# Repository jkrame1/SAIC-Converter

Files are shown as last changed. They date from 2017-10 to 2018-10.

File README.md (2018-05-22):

# Betweener

Teensy 3.2-based Analog to Digital conversion device using 2 4922 12-bit DACs for 4 channels of Analog Output

**NOTE** the most current version of the boards are "DAC 1.1.0.fzz" and "Interface 1.1.0.fzz". Everything else in the Hardware folder is either experimental or older versions.

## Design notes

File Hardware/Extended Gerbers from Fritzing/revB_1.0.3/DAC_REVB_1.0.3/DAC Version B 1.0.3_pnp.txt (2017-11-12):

*Pick And Place List
*Company=
*Author=
*eMail=
*
*Project=DAC Version B 1.0.3
*Date=07:28:19
*CreatedBy=Fritzing 0.9.3b.04.19.5c895d327c44a3114e5fcc9d8260daf0cbb52806
*
*
*Coordinates in mm, always center of component
*Origin 0/0=Lower left corner of PCB
*Rotation in degree (0-360, math. pos.)
*
*No;Value;Package;X;Y;Rotation;Side;Name
1;;;16.5767;-91.6637;-90;Bottom;Teensy 3.2
2;;DIP (Dual Inline) [THT];24.2807;-30.8493;180;Bottom;DAC2
3;100;THT;6.32573;-25.3319;180;Bottom;R27
4;;THT;6.02065;-75.879;0;Bottom;Interface Pots
5;;DIP (Dual Inline) [THT];26.2165;-9.64763;0;Bottom;DAC1
6;100k;THT;29.9497;-66.6498;-135;Bottom;R5
7;;;26.4372;-20.1802;0;Bottom;Jumper5
8;33k;THT;31.656;-85.7319;45;Bottom;R2
9;33k;THT;31.7249;-101.42;45;Bottom;R4
10;33k;THT;31.8699;-69.4215;38.362;Bottom;R6
11;100k;THT;31.2558;-82.936;-135;Bottom;R1
12;;;12.3095;-33.9719;0;Bottom;Jumper10
13;;;1.39628;-103.485;90;Bottom;TXT1
14;;THT;12.6294;-9.03944;180;Bottom;CV Out
15;;to-92;29.768;-92.8947;180;Bottom;Q1
16;;to-92;30.287;-75.2711;180;Bottom;Q3
17;;THT;12.6294;-23.6444;180;Bottom;CV in
18;100;THT;6.41604;-23.1108;180;Bottom;R28
19;;THT;7.48086;-43.6565;0;Bottom;Eurorack Power Header
20;100k;THT;29.9068;-49.879;180;Bottom;R7
21;100;THT;6.14567;-29.7997;180;Bottom;R25
22;;;10.5339;-66.9021;0;Bottom;Jumper11
23;;;27.7194;-55.913;0;Bottom;Jumper8
24;33k;THT;31.0255;-47.7067;0;Bottom;R8
25;;;26.5956;-60.3765;0;Bottom;Jumper9
26;;THT;14.8872;-46.7867;0;Bottom;5V Euro
27;;to-92;29.8738;-107.888;180;Bottom;Q2
28;;THT;29.1394;-53.4894;-90;Bottom;J2
29;220;THT;18.8911;-50.0074;90;Bottom;R_LED
30;;;24.828;-20.2958;0;Bottom;Jumper6
31;;THT;21.0411;-58.7489;-90;Bottom;Expander Header
32;;THT;6.14511;-62.956;-180;Bottom;Power and I2C Header
33;;5 mm [THT];21.6206;-44.1159;180;Bottom;LED1
34;100;THT;6.31472;-27.619;180;Bottom;R26
35;;;20.3318;-47.3394;0;Bottom;Jumper7
36;100k;THT;31.0743;-98.5495;-135;Bottom;R3
37;;DIP (Dual Inline) [THT];6.06326;-11.1781;0;Bottom;CV Output Buffer
38;;to-92;29.6147;-44.3502;0;Bottom;Q4

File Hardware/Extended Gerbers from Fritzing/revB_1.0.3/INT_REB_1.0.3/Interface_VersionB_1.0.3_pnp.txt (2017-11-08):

*Pick And Place List
*Company=
*Author=
*eMail=
*
*Project=Interface_VersionB_1.0.3
*Date=13:25:12
*CreatedBy=Fritzing 0.9.3b.04.19.5c895d327c44a3114e5fcc9d8260daf0cbb52806
*
*
*Coordinates in mm, always center of component
*Origin 0/0=Lower left corner of PCB
*Rotation in degree (0-360, math. pos.)
*
*No;Value;Package;X;Y;Rotation;Side;Name
1;;;18.1328;-55.5065;0;Bottom;IMG3
2;;;30.0567;-10.1535;0;Bottom;Hole43
3;;;22.0487;-64.9518;0;Bottom;Jumper3
4;;;26.87;-61.8238;0;Bottom;Jumper2
5;;;29.9156;-34.0012;0;Bottom;Hole17
6;;PG203J [THT];16.7271;-10.609;180;Bottom;PJ8
7;;;29.7745;-45.9251;0;Bottom;Hole14
8;;PG203J [THT];16.6329;-34.8801;180;Bottom;PJ6
9;;THT;18.8004;-75.2325;0;Bottom;R3
10;100k;THT;4.27426;-85.6496;90;Bottom;R28
11;;;6.06777;-21.8657;0;Bottom;Hole41
12;;PG203J [THT];6.17258;-45.3141;0;Bottom;PJ1
13;100k;THT;22.5002;-87.0187;-90;Bottom;R40
14;66k;THT;34.3733;-85.2904;90;Bottom;R30
15;;PG203J [THT];6.2849;-34.8801;180;Bottom;PJ2
16;;DIP (Dual Inline) [THT];26.1603;-102.729;0;Bottom;INPUT SCALER
17;;;18.0555;-55.5681;0;Bottom;IMG2
18;;;25.0615;-82.5947;0;Bottom;IMG1
19;100k;THT;8.96874;-75.996;90;Bottom;R27
20;;;16.8393;-21.8423;0;Bottom;Hole39
21;;THT;23.4244;-24.2646;180;Bottom;CV IN HEADER
22;66k;THT;2.49626;-88.4654;90;Bottom;R29
23;;;16.7217;-10.083;0;Bottom;Hole42
24;;PG203J [THT];16.4449;-45.4868;0;Bottom;PJ5
25;;THT;6.91444;-54.1096;-90;Bottom;J2
26;;;16.51;-46.0663;0;Bottom;Hole13
27;;THT;9.01151;-100.035;180;Bottom;R1
28;;PG203J [THT];29.9916;-34.8801;180;Bottom;PJ10
29;;;6.27944;-10.083;0;Bottom;Hole44
30;;;9.5562;-1.33729;0;Bottom;TXT1
31;66k;THT;16.0867;-108.35;0;Bottom;R36
32;66k;THT;24.4435;-88.8323;90;Bottom;R31
33;;PG203J [THT];29.9444;-21.2284;0;Bottom;PJ11
34;;THT;29.8509;-76.498;0;Bottom;P
35;66k;THT;34.3924;-107.395;90;Bottom;R33
36;100k;THT;27.4204;-88.9556;90;Bottom;R38
37;;;6.20888;-45.9252;0;Bottom;Hole12
38;100k;THT;10.5726;-73.6772;90;Bottom;R25
39;66k;THT;30.8091;-89.0056;-90;Bottom;R34
40;;;16.4395;-34.0012;0;Bottom;Hole16
41;;THT;23.4244;-9.65962;180;Bottom;CV OUT HEADER
42;66k;THT;19.2131;-97.5915;90;Bottom;R35
43;;PG203J [THT];30.109;-10.7501;180;Bottom;PJ12
44;66k;THT;19.8715;-86.485;90;Bottom;R32
45;;THT;3.66889;-66.5274;0;Bottom;USB Breakout
46;;;3.48082;-109.519;0;Bottom;Hole45
47;;PG203J [THT];6.09667;-21.1452;0;Bottom;PJ3
48;;THT;27.4647;-62.9279;0;Bottom;R4
49;;PG203J [THT];16.6329;-21.2392;0;Bottom;PJ7
50;100k;THT;15.8767;-110.627;0;Bottom;R39
51;;;19.3088;-73.5712;0;Bottom;Jumper1
52;;PG203J [THT];6.43561;-10.5494;180;Bottom;PJ4
53;;THT;11.8767;-87.5704;0;Bottom;R2
54;100k;THT;32.7268;-105.42;-90;Bottom;R26
55;;;6.20888;-34.0718;0;Bottom;Hole15
56;;;30.0095;-21.8423;0;Bottom;Hole40
57;;PG203J [THT];29.7799;-45.3223;0;Bottom;PJ9
58;100k;THT;33.5326;-95.5159;99.81;Bottom;R37

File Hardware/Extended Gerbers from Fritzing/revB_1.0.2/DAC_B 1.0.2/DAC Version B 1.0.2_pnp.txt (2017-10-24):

*Pick And Place List
*Company=
*Author=
*eMail=
*
*Project=DAC Version B 1.0.2
*Date=15:18:01
*CreatedBy=Fritzing 0.9.3b.04.19.5c895d327c44a3114e5fcc9d8260daf0cbb52806
*
*
*Coordinates in mm, always center of component
*Origin 0/0=Lower left corner of PCB
*Rotation in degree (0-360, math. pos.)
*
*No;Value;Package;X;Y;Rotation;Side;Name
1;33k;THT;31.656;-86.296;45;Bottom;R2
2;100k;THT;31.0743;-99.1136;-135;Bottom;R3
3;;;17.9879;-92.2278;-90;Bottom;Teensy 3.2
4;;;26.7942;-56.1872;0;Bottom;Jumper8
5;;DIP (Dual Inline) [THT];6.06326;-11.7422;0;Bottom;CV Output Buffer
6;100;THT;6.41604;-23.9571;180;Bottom;R28
7;;;25.1531;-21.3863;0;Bottom;Jumper5
8;;;11.6887;-69.8016;0;Bottom;Jumper2
9;;;8.92951;-29.8699;0;Bottom;Jumper3
10;;THT;12.6294;-24.2086;180;Bottom;CV in
11;;to-92;30.287;-75.8352;180;Bottom;Q3
12;;DIP (Dual Inline) [THT];26.2165;-11.6229;0;Bottom;DAC1
13;;;1.6462;-102.972;90;Bottom;TXT1
14;;THT;7.29262;-44.6911;0;Bottom;Eurorack Power Header
15;;;11.66;-29.8488;0;Bottom;Jumper4
16;100;THT;6.32573;-26.1782;180;Bottom;R27
17;;THT;19.2538;-60.4419;-90;Bottom;Expander Header
18;33k;THT;31.7249;-101.984;45;Bottom;R4
19;;;25.2067;-21.4033;0;Bottom;Jumper6
20;100k;THT;31.2558;-83.5001;-135;Bottom;R1
21;;to-92;29.8738;-108.452;180;Bottom;Q2
22;;THT;29.1394;-54.0536;-90;Bottom;J2
23;;THT;12.6294;-9.60356;180;Bottom;J3
24;;THT;6.02065;-76.4431;0;Bottom;Interface Pots
25;;;19.3675;-46.2572;0;Bottom;Jumper7
26;;;28.1869;-60.2272;0;Bottom;Jumper9
27;33k;THT;31.0255;-48.2708;0;Bottom;R8
28;;THT;6.14511;-62.109;-180;Bottom;Power and I2C Header
29;;;11.557;-72.1722;0;Bottom;Jumper1
30;;DIP (Dual Inline) [THT];24.2807;-31.4134;180;Bottom;DAC2
31;;to-92;29.6147;-44.9144;0;Bottom;Q4
32;100;THT;6.28678;-31.0694;180;Bottom;R25
33;100;THT;6.38528;-28.677;180;Bottom;R26
34;;to-92;30.3324;-93.4588;180;Bottom;Q1
35;33k;THT;32.7166;-69.1392;51.9312;Bottom;R6
36;100k;THT;31.4079;-60.8639;-90;Bottom;R5
37;100k;THT;30.4713;-50.5136;180;Bottom;R7

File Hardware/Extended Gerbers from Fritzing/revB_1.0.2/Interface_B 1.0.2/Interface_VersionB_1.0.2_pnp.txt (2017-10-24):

*Pick And Place List
*Company=
*Author=
*eMail=
*
*Project=Interface_VersionB_1.0.2
*Date=22:00:41
*CreatedBy=Fritzing 0.9.3b.04.19.5c895d327c44a3114e5fcc9d8260daf0cbb52806
*
*
*Coordinates in mm, always center of component
*Origin 0/0=Lower left corner of PCB
*Rotation in degree (0-360, math. pos.)
*
*No;Value;Package;X;Y;Rotation;Side;Name
1;;THT;29.851;-76.4979;0;Bottom;Pots
2;66k;THT;19.2131;-97.5915;90;Bottom;R35
3;66k;THT;24.4435;-88.8323;90;Bottom;R31
4;100k;THT;22.5002;-87.0187;-90;Bottom;R40
5;;;29.9156;-34.0012;0;Bottom;Hole17
6;;;20.9411;-89.0859;0;Bottom;IMG1
7;;;30.0095;-21.8423;0;Bottom;Hole40
8;100k;THT;10.5726;-73.6772;90;Bottom;R25
9;;;18.1328;-55.5065;0;Bottom;IMG3
10;;PG203J [THT];6.2849;-34.8801;180;Bottom;PJ2
11;;PG203J [THT];6.09667;-21.1452;0;Bottom;PJ3
12;;PG203J [THT];6.17258;-45.3141;0;Bottom;PJ1
13;;PG203J [THT];29.9916;-34.8801;180;Bottom;PJ10
14;66k;THT;19.0813;-86.8237;90;Bottom;R32
15;;THT;6.91444;-54.1096;-90;Bottom;J2
16;;;16.8393;-21.8423;0;Bottom;Hole39
17;100k;THT;15.8767;-110.627;0;Bottom;R39
18;;;30.0567;-10.1535;0;Bottom;Hole43
19;;;22.0486;-64.9517;0;Bottom;Jumper3
20;;PG203J [THT];29.7799;-45.3223;0;Bottom;PJ9
21;66k;THT;16.0867;-108.35;0;Bottom;R36
22;;;3.48082;-109.519;0;Bottom;Hole45
23;100k;THT;8.96874;-75.996;90;Bottom;R27
24;;;16.4395;-34.0012;0;Bottom;Hole16
25;;THT;11.8767;-87.5704;0;Bottom;R2
26;;THT;27.4647;-62.9279;0;Bottom;R4
27;;PG203J [THT];16.4449;-45.4868;0;Bottom;PJ5
28;;;16.7217;-10.083;0;Bottom;Hole42
29;;;18.0555;-55.5681;0;Bottom;IMG2
30;;PG203J [THT];16.6329;-21.2392;0;Bottom;PJ7
31;;PG203J [THT];6.43561;-10.5494;180;Bottom;PJ4
32;;;6.20888;-45.9252;0;Bottom;Hole12
33;;THT;18.8004;-75.2325;0;Bottom;R3
34;;PG203J [THT];29.9444;-21.2284;0;Bottom;PJ11
35;;;19.3087;-73.5712;0;Bottom;Jumper1
36;;;29.7745;-45.9251;0;Bottom;Hole14
37;100k;THT;27.4204;-88.9555;90;Bottom;R38
38;;;6.20888;-34.0718;0;Bottom;Hole15
39;;DIP (Dual Inline) [THT];26.1603;-102.729;0;Bottom;INPUT SCALER
40;;;16.51;-46.0663;0;Bottom;Hole13
41;;PG203J [THT];16.6329;-34.8801;180;Bottom;PJ6
42;100k;THT;33.589;-95.2337;102.557;Bottom;R37
43;66k;THT;30.8091;-89.0056;-90;Bottom;R34
44;;THT;23.4244;-24.2646;180;Bottom;CV IN HEADER
45;;THT;3.66889;-66.5274;0;Bottom;USB Breakout
46;;THT;23.4244;-9.65962;180;Bottom;CV OUT HEADER
47;;PG203J [THT];16.7271;-10.609;180;Bottom;PJ8
48;66k;THT;2.49626;-88.4654;90;Bottom;R29
49;66k;THT;34.3924;-107.395;90;Bottom;R33
50;66k;THT;34.3733;-85.2904;90;Bottom;R30
51;100k;THT;4.27435;-85.6495;90;Bottom;R28
52;;;26.8699;-61.8237;0;Bottom;Jumper2
53;100k;THT;32.7268;-105.42;-90;Bottom;R26
54;;;6.06777;-21.8657;0;Bottom;Hole41
55;;;6.27944;-10.083;0;Bottom;Hole44
56;;PG203J [THT];30.109;-10.7501;180;Bottom;PJ12
57;;THT;9.01151;-100.035;180;Bottom;R1

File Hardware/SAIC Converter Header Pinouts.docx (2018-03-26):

Betweener Header Pinouts

Betweener V1.1.0

Expansion Header
PIN14 +3.3V | PIN13 GND | PIN12 D8(LED) | PIN11 D33(touch) | PIN10 D31/A20 (serial2 Tx for DINMIDI) | PIN9 D25(touch)PWM | PIN8 D27/A16
PIN1 +5VNC | PIN2 GND | PIN3 A14/DAC | PIN4 D32(touch)/PWM | PIN5 D24 | PIN6 D26/A15(serial2 Rx for DIN MIDI) | PIN7 D28/A17

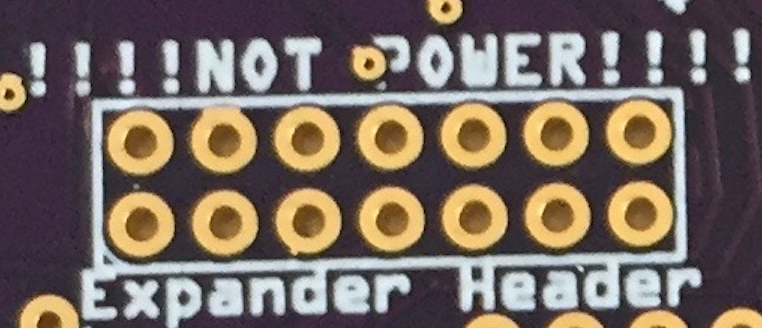
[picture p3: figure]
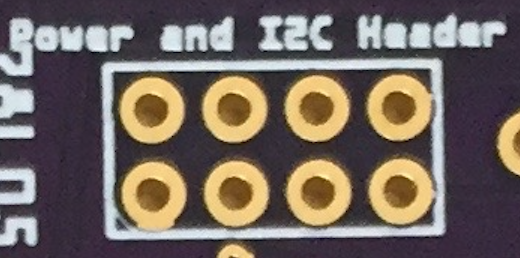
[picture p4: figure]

(bottom end) I²C Header
PIN8 GND | PIN7 +5V | PIN6 +3.3V | PIN5 D29/A18 (SCL1)
PIN1 GND | PIN2 +5V | PIN3 +3.3V | PIN4 D30/A19 (SDA1)

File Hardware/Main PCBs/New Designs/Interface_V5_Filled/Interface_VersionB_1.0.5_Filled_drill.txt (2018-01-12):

; NON-PLATED HOLES START AT T1
; THROUGH (PLATED) HOLES START AT T100
M48
INCH
T1C0.118110
T2C0.125984
T100C0.039370
T101C0.041361
T102C0.125984
T103C0.061825
T104C0.015748
T105C0.035000
T106C0.061867
T107C0.031497
T108C0.088356
T109C0.050165
T110C0.038000
T111C0.041333
%
T1
X002444Y012914
X006583Y003469
X006499Y017636
X002472Y003469
X011833Y003497
X011814Y008099
X006629Y008099
X002444Y017580
X002388Y008108
T2
X011722Y017580
X011777Y012886
X006472Y012886
T100
X008799Y039944
X011799Y038944
X011799Y042944
X011799Y039944
X008799Y036944
X008799Y040944
X008799Y037944
X011799Y036944
X008799Y041944
X011799Y040944
X008799Y038944
X011799Y037944
X008799Y042944
X011799Y041944
T101
X002776Y032972
X005447Y039887
X005502Y028115
X008913Y023270
T102
X001370Y042617
T103
X006550Y004740
X011819Y004796
X002434Y006760
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

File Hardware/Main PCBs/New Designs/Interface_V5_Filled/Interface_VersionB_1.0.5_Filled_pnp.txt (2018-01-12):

*Pick And Place List
*Company=
*Author=
*eMail=
*
*Project=Interface_VersionB_1.0.5_Filled
*Date=14:42:28
*CreatedBy=Fritzing 0.9.3b.04.19.5c895d327c44a3114e5fcc9d8260daf0cbb52806
*
*
*Coordinates in mm, always center of component
*Origin 0/0=Lower left corner of PCB
*Rotation in degree (0-360, math. pos.)
*
*No;Value;Package;X;Y;Rotation;Side;Name
1;;;7.8994;-88.8828;0;Bottom;Copper Fill82
2;;;22.7838;-74.4937;0;Bottom;Copper Fill70
3;;;27.686;-3.88168;0;Bottom;Copper Fill45
4;;;3.48082;-108.249;0;Bottom;Hole45
5;;;15.5194;-12.0732;0;Bottom;Copper Fill101
6;;;20.1041;-80.7929;0;Bottom;Copper Fill93
7;;;31.6738;-14.9561;0;Bottom;Copper Fill38
8;100k;THT;3.99203;-84.6619;90;Bottom;R28
9;;;34.0614;-94.1786;0;Bottom;Copper Fill15
10;;THT;23.4244;-8.38962;180;Bottom;CV OUT HEADER
11;;;15.4178;-41.588;0;Bottom;Copper Fill107
12;;;25.3492;-7.13288;0;Bottom;Copper Fill40
13;;THT;18.8004;-73.9625;0;Bottom;R3
14;66k;THT;1.93181;-87.4776;90;Bottom;R29
15;220;THT;21.0256;-54.1553;0;Bottom;RLED
16;;;17.8308;-89.5051;0;Bottom;Copper Fill18
17;;THT;9.01151;-98.7647;180;Bottom;R1
18;;;22.2885;-82.9519;0;Bottom;Copper Fill94
19;;;2.286;-104.44;0;Bottom;Copper Fill6
20;;;16.51;-29.6881;0;Bottom;Copper Fill33
21;;;32.893;-106.421;0;Bottom;Copper Fill5
22;;;20.1041;-80.7929;0;Bottom;Copper Fill51
23;;;16.4395;-32.7312;0;Bottom;Hole16
24;;;1.8669;-84.5775;0;Bottom;Copper Fill90
25;;;33.8582;-3.19588;0;Bottom;Copper Fill44
26;;THT;6.63222;-55.3091;90;Bottom;J3
27;;;15.4178;-36.3556;0;Bottom;Copper Fill109
28;;;16.6497;-18.3851;0;Bottom;Copper Fill103
29;;PG203J [THT];6.17258;-44.0441;0;Bottom;PJ1
30;;;18.1328;-54.2365;0;Bottom;IMG3
31;100k;THT;22.3591;-85.8193;-90;Bottom;R40
32;;5 mm [THT];12.3194;-61.6163;180;Bottom;LED1
33;;PG203J [THT];6.2849;-33.6101;180;Bottom;PJ2
34;;;34.2138;-74.6715;0;Bottom;Copper Fill23
35;;;16.51;-44.7963;0;Bottom;Hole13
36;;THT;27.4647;-61.6579;0;Bottom;R4
37;;;32.3596;-96.2614;0;Bottom;Copper Fill9
38;;;33.6804;-82.7741;0;Bottom;Copper Fill68
39;;PG203J [THT];16.6329;-33.6101;180;Bottom;PJ6
40;;;33.7312;-77.8719;0;Bottom;Copper Fill72
41;;;15.0368;-97.2774;0;Bottom;Copper Fill13
42;;PG203J [THT];16.6329;-19.9692;0;Bottom;PJ7
43;;;15.748;-14.7148;0;Bottom;Copper Fill79
44;;;23.495;-64.2448;0;Bottom;Copper Fill56
45;;;11.684;-66.5435;0;Bottom;Copper Fill27
46;;;17.7292;-17.3056;0;Bottom;Copper Fill105
47;;;1.0922;-83.7012;0;Bottom;Copper Fill91
48;;THT;23.4244;-22.9946;180;Bottom;CV IN HEADER
49;;;20.2184;-66.7467;0;Bottom;Copper Fill74
50;;;16.4973;-42.6421;0;Bottom;Copper Fill59
51;;;31.623;-77.9227;0;Bottom;Copper Fill22
52;;;26.4414;-5.22788;0;Bottom;Copper Fill43
53;;;16.4973;-42.6421;0;Bottom;Copper Fill106
54;;;16.9164;-94.839;0;Bottom;Copper Fill64
55;;;29.083;-14.8164;0;Bottom;Copper Fill78
56;;;21.3614;-83.663;0;Bottom;Copper Fill24
57;66k;THT;25.5724;-85.8689;90;Bottom;R31
58;;;25.4889;-81.2501;0;Bottom;Copper Fill50
59;;;12.7889;-110.689;0;Bottom;Copper Fill96
60;;;7.0866;-14.6132;0;Bottom;Copper Fill86
61;;PG203J [THT];30.109;-9.48008;180;Bottom;PJ12
62;;;28.9306;-38.794;0;Bottom;Copper Fill47
63;;;28.0924;-28.7991;0;Bottom;Copper Fill35
64;;;5.334;-38.794;0;Bottom;Copper Fill87
65;;;11.8618;-109.761;0;Bottom;Copper Fill97
66;100k;THT;16.4412;-108.416;19.9401;Bottom;R39
67;;;6.27944;-8.81296;0;Bottom;Hole44
68;;;16.5989;-11.0191;0;Bottom;Copper Fill100
69;;;33.9374;-30.2617;0;Bottom;Via3
70;66k;THT;34.0538;-104.375;90;Bottom;R33
71;66k;THT;20.1538;-85.4267;90;Bottom;R32
72;;;18.0086;-51.3288;0;Bottom;Copper Fill41
73;;;27.7368;-96.1344;0;Bottom;Copper Fill14
74;;;15.4178;-36.3556;0;Bottom;Copper Fill61
75;;;9.5562;-1.19618;0;Bottom;TXT1
76;66k;THT;30.8091;-87.7356;-90;Bottom;R34
77;;;30.0095;-20.5723;0;Bottom;Hole40
78;;PG203J [THT];29.9444;-19.9584;0;Bottom;PJ11
79;;;6.06777;-20.5957;0;Bottom;Hole41
80;;THT;29.8509;-75.228;0;Bottom;P
81;;;17.3482;-38.9464;0;Bottom;Copper Fill84
82;;;21.1074;-91.0037;0;Bottom;Copper Fill65
83;;DIP (Dual Inline) [THT];26.1603;-101.459;0;Bottom;INPUT SCALER
84;;;10.0838;-101.113;0;Bottom;Copper Fill8
85;;;15.5956;-17.3056;0;Bottom;Copper Fill104
86;;PG203J [THT];6.09667;-19.8752;0;Bottom;PJ3
87;;;15.5194;-79.2943;0;Bottom;Copper Fill71
88;66k;THT;34.091;-83.1737;90;Bottom;R30
89;;;25.7575;-75.0035;0;Bottom;Via6
90;;;7.0104;-63.0129;0;Bottom;Copper Fill75
91;66k;THT;15.8045;-106.045;20.437;Bottom;R36
92;;;25.2222;-25.2431;0;Bottom;Copper Fill36
93;100k;THT;33.4762;-93.5122;99.81;Bottom;R37
94;;;11.6078;-83.7901;0;Bottom;Copper Fill19
95;;;31.75;-23.1349;0;Bottom;Copper Fill37
96;;;34.798;-79.3832;0;Bottom;Copper Fill49
97;;;28.9814;-101.481;0;Bottom;Copper Fill89
98;;;16.7217;-8.81296;0;Bottom;Hole42
99;;;17.653;-12.0732;0;Bottom;Copper Fill55
100;;;18.0555;-54.2981;0;Bottom;IMG2
101;;;24.13;-90.5211;0;Bottom;Copper Fill17
102;;;22.1996;-8.37748;0;Bottom;Copper Fill39
103;;;31.75;-104.516;0;Bottom;Copper Fill7
104;;;16.4973;-35.3015;0;Bottom;Copper Fill60
105;;THT;3.38667;-65.2574;0;Bottom;USB Breakout
106;;;27.5082;-91.791;0;Bottom;Copper Fill69
107;;;6.20888;-44.6552;0;Bottom;Hole12
108;;;10.7696;-81.3263;0;Bottom;Copper Fill21
109;;PG203J [THT];16.4449;-44.2168;0;Bottom;PJ5
110;;;5.2578;-14.6132;0;Bottom;Copper Fill85
111;66k;THT;19.2131;-95.4748;90;Bottom;R35
112;;;22.2885;-81.1993;0;Bottom;Copper Fill95
113;;;27.3685;-84.7807;0;Bottom;Copper Fill99
114;;;30.0567;-8.88352;0;Bottom;Hole43
115;;THT;11.8767;-86.3004;0;Bottom;R2
116;;PG203J [THT];29.7799;-44.0523;0;Bottom;PJ9
117;;;32.893;-98.9792;0;Bottom;Copper Fill67
118;;PG203J [THT];29.9916;-33.6101;180;Bottom;PJ10
119;;;23.0124;-68.7787;0;Bottom;Copper Fill26
120;;;10.3378;-56.5613;0;Bottom;Copper Fill31
121;;;5.0038;-56.9423;0;Bottom;Copper Fill30
122;;;16.7132;-99.5126;0;Bottom;Copper Fill10
123;;;28.575;-62.8605;0;Bottom;Copper Fill28
124;100k;THT;32.2752;-106.634;-90;Bottom;R26
125;;;11.5062;-59.8252;0;Bottom;Copper Fill62
126;;PG203J [THT];16.7271;-9.33897;180;Bottom;PJ8
127;;;19.7612;-95.5248;0;Bottom;Copper Fill12
128;;;26.2636;-103.069;0;Bottom;Copper Fill3
129;;;17.0434;-86.1777;0;Bottom;Copper Fill20
130;;;31.115;-71.3441;0;Bottom;Copper Fill25
131;100k;THT;10.5726;-72.4072;90;Bottom;R25
132;;;6.9977;-89.8099;0;Bottom;Copper Fill81
133;;;23.6219;-30.2052;0;Bottom;Via1
134;;;17.526;-14.7148;0;Bottom;Copper Fill80
135;;;29.7745;-44.6551;0;Bottom;Hole14
136;;;22.1996;-5.83748;0;Bottom;Copper Fill42
137;;;6.20888;-32.8018;0;Bottom;Hole15
138;;;18.0086;-30.2723;0;Bottom;Copper Fill76
139;;;7.0866;-38.794;0;Bottom;Copper Fill88
140;;;27.0256;-41.8547;0;Bottom;Copper Fill77
141;;;16.4973;-35.3015;0;Bottom;Copper Fill108
142;;;33.1724;-98.903;0;Bottom;Copper Fill11
143;;;15.5194;-12.0732;0;Bottom;Copper Fill54
144;;;9.8044;-82.8756;0;Bottom;Copper Fill73
145;;;33.0708;-26.5893;0;Bottom;Copper Fill34
146;;;15.621;-38.9464;0;Bottom;Copper Fill83
147;;;21.1582;-91.4355;0;Bottom;Copper Fill16
148;;;13.716;-109.761;0;Bottom;Copper Fill98
149;;;20.828;-85.7713;0;Bottom;Copper Fill66
150;;;3.8354;-28.9769;0;Bottom;Copper Fill32
151;;;7.9248;-109.088;0;Bottom;Copper Fill1
152;;;11.7593;-4.01527;0;Bottom;Via8
153;;;22.2885;-81.1993;0;Bottom;Copper Fill52
154;;;16.5989;-11.0191;0;Bottom;Copper Fill53
155;;;20.0755;-64.5141;0;Bottom;Via5
156;100k;THT;8.96874;-74.726;90;Bottom;R27
157;;;16.8393;-20.5723;0;Bottom;Hole39
158;;;17.8308;-58.8219;0;Bottom;Copper Fill29
159;;;17.653;-12.0732;0;Bottom;Copper Fill102
160;100k;THT;27.4204;-87.6856;90;Bottom;R38
161;;;15.5956;-17.3056;0;Bottom;Copper Fill58
162;;;5.2578;-14.6132;0;Bottom;Copper Fill48
163;;;17.399;-109.622;0;Bottom;Copper Fill2
164;;PG203J [THT];6.43561;-9.27942;180;Bottom;PJ4
165;;THT;6.91444;-52.8396;-90;Bottom;J2
166;;;17.145;-102.256;0;Bottom;Copper Fill63
167;;;15.7668;-77.7317;0;Bottom;Via7
168;;;29.9156;-32.7312;0;Bottom;Hole17
169;;;21.5899;-19.9137;0;Bottom;Via9
170;;;16.6497;-18.3851;0;Bottom;Copper Fill57
171;;;34.0614;-110.028;0;Bottom;Copper Fill4
172;;;25.4846;-31.7436;0;Bottom;Via2
173;;;30.7086;-38.9464;0;Bottom;Copper Fill46
174;;;20.1041;-82.5455;0;Bottom;Copper Fill92

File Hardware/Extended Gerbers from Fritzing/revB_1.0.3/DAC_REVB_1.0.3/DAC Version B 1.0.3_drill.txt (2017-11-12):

; NON-PLATED HOLES START AT T1
; THROUGH (PLATED) HOLES START AT T100
M48
INCH
T100C0.039370
T101C0.038889
T102C0.041000
T103C0.035000
T104C0.031497
T105C0.032000
T106C0.038000
%
T100
X003887Y005400
X000887Y003400
X003887Y006400
X000887Y004400
X003887Y007400
X003887Y001400
X000887Y005400
X003887Y002400
X000887Y006400
X003887Y003400
X000887Y007400
X000887Y001400
X003887Y004400
X000887Y002400
T101
X004526Y042775
X006526Y042775
X006540Y039775
X004526Y034775
X005526Y042775
X007526Y042775
X009526Y042775
X003526Y042775
X009526Y034775
X003526Y034775
X006540Y040775
X008526Y042775
X005526Y039775
X009526Y039775
X003526Y039775
X006540Y037775
X004526Y032775
X005526Y040775
X009526Y040775
X003526Y040775
X009526Y032775
X003526Y032775
X005526Y037775
X009526Y037775
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

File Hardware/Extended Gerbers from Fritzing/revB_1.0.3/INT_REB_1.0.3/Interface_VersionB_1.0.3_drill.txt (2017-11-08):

; NON-PLATED HOLES START AT T1
; THROUGH (PLATED) HOLES START AT T100
M48
INCH
T1C0.118110
T2C0.125984
T100C0.041333
T101C0.039370
T102C0.041361
T103C0.125984
T104C0.061825
T105C0.035000
T106C0.061867
T107C0.088356
T108C0.050165
T109C0.038000
%
T1
X006499Y018136
X006629Y008599
X002388Y008608
X002444Y018080
X006583Y003969
X002472Y003969
X002444Y013414
X011833Y003997
X011814Y008599
T2
X006472Y013386
X011722Y018080
X011777Y013386
T100
X002776Y034472
X008913Y025771
X005447Y039387
X002776Y035472
X005502Y029615
X005502Y030615
X008913Y024771
X005447Y038387
T101
X011799Y039444
X011799Y043444
X008799Y040444
X008799Y037444
X008799Y041444
X011799Y040444
X008799Y038444
X011799Y037444
X008799Y042444
X011799Y041444
X008799Y039444
X011799Y038444
X008799Y043444
X011799Y042444
T102
X005502Y028615
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

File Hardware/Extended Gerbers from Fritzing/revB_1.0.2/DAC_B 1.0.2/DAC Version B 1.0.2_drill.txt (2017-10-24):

; NON-PLATED HOLES START AT T1
; THROUGH (PLATED) HOLES START AT T100
M48
INCH
T100C0.032000
T101C0.038000
T102C0.039370
T103C0.038889
T104C0.041000
T105C0.035000
%
T100
X011941Y036259
X011441Y037009
X012441Y037009
X011261Y042912
X011659Y018217
X012261Y042912
X011159Y017467
X012159Y017467
X011424Y030071
X012424Y030071
X011761Y042162
X011924Y029321
T101
X003371Y018094
X004972Y009530
X001919Y025952
X003371Y021094
X002370Y030095
X003371Y017094
X004972Y008530
X001919Y024952
X003371Y020094
X005580Y024296
X004972Y011530
X003371Y016094
X004972Y007530
X001919Y023952
X005580Y023296
X004972Y010530
X011472Y021280
X008580Y024296
X003371Y015094
X001919Y022952
X008580Y023296
X003371Y014094
X002919Y025952
X002919Y024952
X006580Y024296
X002919Y023952
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

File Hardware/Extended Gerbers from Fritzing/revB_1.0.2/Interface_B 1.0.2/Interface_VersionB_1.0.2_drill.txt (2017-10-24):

; NON-PLATED HOLES START AT T1
; THROUGH (PLATED) HOLES START AT T100
M48
INCH
T1C0.118110
T2C0.125984
T100C0.041333
T101C0.039370
T102C0.041361
T103C0.125984
T104C0.061825
T105C0.035000
T106C0.061867
T107C0.088356
T108C0.050165
T109C0.038000
%
T1
X011833Y003997
X011814Y008599
X006499Y018136
X006629Y008599
X002388Y008608
X002472Y003969
X002444Y018080
X006583Y003969
X002444Y013414
T2
X011722Y018080
X011777Y013386
X006472Y013386
T100
X005447Y039387
X002776Y035472
X005502Y029615
X005502Y030615
X008913Y024771
X005447Y038387
X002776Y034472
X008913Y025771
T101
X011799Y038444
X008799Y043444
X011799Y042444
X011799Y039444
X011799Y043444
X008799Y040444
X008799Y037444
X008799Y041444
X011799Y040444
X008799Y038444
X011799Y037444
X008799Y042444
X011799Y041444
X008799Y039444
T102
X008913Y023770
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

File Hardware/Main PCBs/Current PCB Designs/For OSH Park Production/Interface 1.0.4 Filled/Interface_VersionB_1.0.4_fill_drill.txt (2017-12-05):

; NON-PLATED HOLES START AT T1
; THROUGH (PLATED) HOLES START AT T100
M48
INCH
T1C0.125984
T2C0.118110
T100C0.125984
T101C0.061825
T102C0.015748
T103C0.035000
T104C0.061867
T105C0.088356
T106C0.050165
T107C0.038000
T108C0.041333
T109C0.039370
T110C0.041361
%
T1
X006472Y012886
X011722Y017580
X011777Y012886
T2
X002444Y012914
X006499Y017636
X002472Y003469
X006583Y003469
X011833Y003497
X011814Y008099
X002444Y017580
X006629Y008099
X002388Y008108
T100
X001370Y042617
T101
X006509Y016344
X006550Y004740
X006583Y006797
X011819Y004796
X002434Y006760
X011823Y006793
X011773Y014296
X002499Y004717
X002439Y014296
X006513Y014296
X011759Y016279
X002464Y016276
T102
X009972Y007775
X010140Y029528
X013361Y011913
X008722Y012719
X004629Y001580
X006207Y030602
X007903Y025399
X008411Y011180
T103
X001571Y031831
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

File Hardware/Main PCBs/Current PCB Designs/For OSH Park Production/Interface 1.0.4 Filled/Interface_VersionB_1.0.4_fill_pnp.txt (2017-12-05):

*Pick And Place List
*Company=
*Author=
*eMail=
*
*Project=Interface_VersionB_1.0.4_fill
*Date=07:41:39
*CreatedBy=Fritzing 0.9.3b.04.19.5c895d327c44a3114e5fcc9d8260daf0cbb52806
*
*
*Coordinates in mm, always center of component
*Origin 0/0=Lower left corner of PCB
*Rotation in degree (0-360, math. pos.)
*
*No;Value;Package;X;Y;Rotation;Side;Name
1;;PG203J [THT];6.43561;-9.27942;180;Bottom;PJ4
2;;DIP (Dual Inline) [THT];26.1603;-101.459;0;Bottom;INPUT SCALER
3;100k;THT;3.99203;-84.6619;90;Bottom;R28
4;;;17.7038;-12.0731;0;Bottom;Copper Fill90
5;;;30.0567;-8.88352;0;Bottom;Hole43
6;;;18.0086;-26.386;0;Bottom;Copper Fill67
7;;;27.1272;-46.6552;0;Bottom;Copper Fill26
8;;;6.9977;-89.9114;0;Bottom;Copper Fill69
9;;PG203J [THT];29.9444;-19.9584;0;Bottom;PJ11
10;;;17.5768;-14.7147;0;Bottom;Copper Fill72
11;;;13.7668;-109.761;0;Bottom;Copper Fill87
12;;;28.829;-92.2482;0;Bottom;Copper Fill13
13;;;3.48082;-108.249;0;Bottom;Hole45
14;;PG203J [THT];6.17258;-44.0441;0;Bottom;PJ1
15;;;6.20888;-32.8018;0;Bottom;Hole15
16;;;15.5194;-17.3055;0;Bottom;Copper Fill91
17;;;15.5194;-17.3055;0;Bottom;Copper Fill47
18;66k;THT;15.8045;-106.045;20.437;Bottom;R36
19;;;33.0454;-106.498;0;Bottom;Copper Fill5
20;;;16.9672;-94.966;0;Bottom;Copper Fill56
21;;;6.5278;-54.6816;0;Bottom;Copper Fill28
22;;;15.7668;-77.7317;0;Bottom;Via7
23;66k;THT;30.8091;-87.7356;-90;Bottom;R34
24;100k;THT;32.2752;-106.634;-90;Bottom;R26
25;;;9.525;-94.1786;0;Bottom;Copper Fill12
26;66k;THT;25.5724;-85.8689;90;Bottom;R31
27;;;15.7734;-79.2434;0;Bottom;Copper Fill61
28;;;6.20888;-44.6552;0;Bottom;Hole12
29;;;16.8393;-20.5723;0;Bottom;Hole39
30;;THT;27.4647;-61.6579;0;Bottom;R4
31;;;17.8054;-38.9336;0;Bottom;Copper Fill31
32;100k;THT;10.5726;-72.4072;90;Bottom;R25
33;;;9.5562;-1.19618;0;Bottom;TXT1
34;;;22.0472;-69.8708;0;Bottom;Copper Fill21
35;;;1.8669;-84.679;0;Bottom;Copper Fill81
36;;;17.78;-17.3055;0;Bottom;Copper Fill92
37;;;15.4686;-12.0731;0;Bottom;Copper Fill44
38;;;15.5702;-38.9463;0;Bottom;Copper Fill73
39;;;26.2128;-103.272;0;Bottom;Copper Fill3
40;;;31.75;-14.4226;0;Bottom;Copper Fill35
41;;;25.0615;-81.3247;0;Bottom;IMG1
42;;;16.51;-44.7963;0;Bottom;Hole13
43;;;18.1328;-54.2365;0;Bottom;IMG3
44;;;2.921;-3.5768;0;Bottom;Copper Fill37
45;;;34.2392;-94.331;0;Bottom;Copper Fill11
46;;;17.7038;-12.0731;0;Bottom;Copper Fill45
47;;;9.398;-81.0722;0;Bottom;Copper Fill63
48;;;10.1092;-101.341;0;Bottom;Copper Fill7
49;66k;THT;34.091;-83.1737;90;Bottom;R30
50;;;24.0792;-90.8004;0;Bottom;Copper Fill15
51;66k;THT;19.2131;-95.4748;90;Bottom;R35
52;;;22.8854;-82.4946;0;Bottom;Copper Fill19
53;;;32.9692;-105.507;0;Bottom;Copper Fill54
54;;;25.4889;-81.1484;0;Bottom;Copper Fill43
55;;PG203J [THT];6.09667;-19.8752;0;Bottom;PJ3
56;;;15.6972;-14.7147;0;Bottom;Copper Fill71
57;100k;THT;8.96874;-74.726;90;Bottom;R27
58;;;30.7594;-38.9463;0;Bottom;Copper Fill39
59;;;28.194;-87.4476;0;Bottom;Copper Fill57
60;;;15.2908;-27.8846;0;Bottom;Copper Fill29
61;100k;THT;27.4204;-87.6856;90;Bottom;R38
62;;;25.5778;-2.7386;0;Bottom;Copper Fill38
63;;;23.5966;-64.2447;0;Bottom;Copper Fill46
64;100k;THT;16.4412;-108.416;19.9401;Bottom;R39
65;;PG203J [THT];29.9916;-33.6101;180;Bottom;PJ10
66;;;4.3942;-28.3164;0;Bottom;Copper Fill34
67;;;12.7889;-110.689;0;Bottom;Copper Fill85
68;;;20.7518;-85.4918;0;Bottom;Copper Fill58
69;;;25.3293;-19.7492;0;Bottom;Via4
70;;;6.06777;-20.5957;0;Bottom;Hole41
71;;;1.9558;-104.542;0;Bottom;Copper Fill6
72;;;11.9253;-53.8942;0;Bottom;Copper Fill79
73;;;17.9324;-42.5912;0;Bottom;Copper Fill30
74;;;27.432;-73.884;0;Bottom;Copper Fill22
75;;;17.78;-17.3055;0;Bottom;Copper Fill48
76;;;34.4678;-75.6366;0;Bottom;Copper Fill20
77;;;6.27944;-8.81296;0;Bottom;Hole44
78;;;34.798;-79.3831;0;Bottom;Copper Fill42
79;66k;THT;1.93181;-87.4776;90;Bottom;R29
80;;THT;3.38667;-65.2574;0;Bottom;USB Breakout
81;;;33.0708;-26.7416;0;Bottom;Copper Fill33
82;;;29.0322;-14.8163;0;Bottom;Copper Fill68
83;;;11.4554;-66.1116;0;Bottom;Copper Fill23
84;;;9.906;-70.6328;0;Bottom;Copper Fill27
85;;;29.9156;-32.7312;0;Bottom;Hole17
86;;;15.367;-36.3555;0;Bottom;Copper Fill50
87;;;7.1374;-14.6131;0;Bottom;Copper Fill76
88;;;21.1074;-91.2322;0;Bottom;Copper Fill14
89;66k;THT;19.8715;-85.215;90;Bottom;R32
90;;;27.0002;-41.8292;0;Bottom;Copper Fill65
91;;;20.0755;-64.5141;0;Bottom;Via5
92;;;28.8798;-38.7939;0;Bottom;Copper Fill40
93;;;15.367;-41.5879;0;Bottom;Copper Fill93
94;;THT;6.91444;-52.8396;-90;Bottom;J2
95;100k;THT;22.2179;-85.7487;-90;Bottom;R40
96;;;28.2194;-80.0054;0;Bottom;Copper Fill60
97;;;5.207;-14.6131;0;Bottom;Copper Fill41
98;;;19.4056;-63.5462;0;Bottom;Copper Fill24
99;;;5.2832;-38.7939;0;Bottom;Copper Fill77
100;;;17.4752;-86.457;0;Bottom;Copper Fill16
101;;;16.7217;-8.81296;0;Bottom;Hole42
102;;;7.1374;-38.7939;0;Bottom;Copper Fill78
103;;;30.0095;-20.5723;0;Bottom;Hole40
104;;;22.1361;-82.9518;0;Bottom;Copper Fill84
105;;;17.5514;-109.8;0;Bottom;Copper Fill4
106;;;11.811;-109.761;0;Bottom;Copper Fill86
107;;;11.8872;-86.711;0;Bottom;Copper Fill17
108;;;1.0922;-83.7011;0;Bottom;Copper Fill82
109;;THT;23.4244;-8.38962;180;Bottom;CV OUT HEADER
110;;;16.4973;-35.2252;0;Bottom;Copper Fill94
111;;;16.4395;-32.7312;0;Bottom;Hole16
112;;;26.3144;-100.884;0;Bottom;Copper Fill52
113;;;32.9692;-94.9152;0;Bottom;Copper Fill55
114;;;33.1724;-4.3134;0;Bottom;Copper Fill36
115;;;22.1543;-32.3081;0;Bottom;Via2
116;;;25.7575;-75.0035;0;Bottom;Via6
117;;THT;29.8509;-75.228;0;Bottom;P
118;;;21.3641;-28.399;0;Bottom;Via1
119;66k;THT;34.0538;-104.375;90;Bottom;R33
120;;;17.8054;-34.9966;0;Bottom;Copper Fill32
121;;;18.0555;-54.2981;0;Bottom;IMG2
122;;PG203J [THT];6.2849;-33.6101;180;Bottom;PJ2
123;;THT;11.8767;-86.3004;0;Bottom;R2
124;;;27.3685;-84.8822;0;Bottom;Copper Fill88
125;;;33.7058;-83.0026;0;Bottom;Copper Fill59
126;;THT;9.01151;-98.7647;180;Bottom;R1
127;;THT;23.4244;-22.9946;180;Bottom;CV IN HEADER
128;;;28.7274;-62.8096;0;Bottom;Copper Fill25
129;;;16.4973;-35.2252;0;Bottom;Copper Fill49
130;;;32.2834;-93.569;0;Bottom;Copper Fill10
131;;PG203J [THT];30.109;-9.48008;180;Bottom;PJ12
132;;;17.0942;-102.51;0;Bottom;Copper Fill51
133;;;7.8232;-109.368;0;Bottom;Copper Fill1
134;;;11.7593;-4.01527;0;Bottom;Via8
135;;PG203J [THT];16.7271;-9.33897;180;Bottom;PJ8
136;;;8.6106;-81.6056;0;Bottom;Copper Fill18
137;;PG203J [THT];16.4449;-44.2168;0;Bottom;PJ5
138;;PG203J [THT];16.6329;-19.9692;0;Bottom;PJ7
139;;PG203J [THT];16.6329;-33.6101;180;Bottom;PJ6
140;;;34.3408;-110.13;0;Bottom;Copper Fill2
141;;;5.207;-14.6131;0;Bottom;Copper Fill75
142;;THT;18.8004;-73.9625;0;Bottom;R3
143;;PG203J [THT];29.7799;-44.0523;0;Bottom;PJ9
144;;;27.6606;-96.0836;0;Bottom;Copper Fill9
145;;;15.4686;-12.0731;0;Bottom;Copper Fill89
146;;;28.8798;-101.481;0;Bottom;Copper Fill80
147;;;33.9374;-30.2617;0;Bottom;Via3
148;;;29.7745;-44.6551;0;Bottom;Hole14
149;;;17.399;-38.9463;0;Bottom;Copper Fill74
150;100k;THT;33.4762;-93.5122;99.81;Bottom;R37
151;;;19.7993;-82.4438;0;Bottom;Copper Fill83
152;;;15.367;-36.3555;0;Bottom;Copper Fill95
153;;;20.3454;-66.5688;0;Bottom;Copper Fill64
154;;;22.8092;-73.6554;0;Bottom;Copper Fill62
155;;;7.493;-60.1172;0;Bottom;Copper Fill66
156;;;19.7104;-95.4994;0;Bottom;Copper Fill8
157;;;34.3408;-110.13;0;Bottom;Copper Fill53
158;;;8.001;-88.8827;0;Bottom;Copper Fill70

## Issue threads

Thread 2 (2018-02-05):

Betweener library SPI.begin(); in the begin() funtion causes conflict with audio on the audio shield

jkrame1, 2018-02-05:
When the Betweener library begin(); function is called in a sketch using the STGL5000 codec controller, audio functionality is broken for the audio shield. See the "First Example of Betweener Library with Audio Shield" example for more detail.  In this example, the samples in memory still play, but no audio is produced at the output.

There is probably an easy way to handle this to avoid conflicts or automate when the SPI.begin() is needed and when it will cause problems, but I don't know the answer yet.

kschaffer, 2018-02-05:
Hmmm... OK, this sounds like something I need to catch up on, and it will take a couple of days to see if I can replicate the issue.  I remember having some odd issues with audio functionality breaking rather randomly back in the beginning of playing around with the audio shield... keep me posted if you figure stuff out, and in the mean time I will see if I can get that example running (and breaking).  thanks...
k.

jkrame1, 2018-02-05:
Cool. I think I found where the problem lives, I just don’t know enough to fix it without breaking something else in the process. Using the begin(); function killed the audio in the two audio shield tutorials to which I tried to add Betweener library control. But in both cases everything else (LEDs, serial, trigger inputs) worked fine from the original code and the added Betweener hardware.  I don’t want to go hacking at the library if there may be an obvious answer, but dropping the one line from the .cpp fixed both frankensteins.

No rush. Thanks for taking a look when you get (find? make? create?) time.

JMK

kschaffer, 2018-02-05:
This might be really obvious and stupid, but did you experiment with order?  Like, doing the begin() function before invoking the various .enable() and whatnot in that sketch?

I don't have an audio shield hooked up to a betweener at the moment but I should be able to test this with my breadboarded Teensy since the symptoms are at a pretty basic level.  And I'll definitely make time... having bugs to fix actually works really well to stop me from spinning my wheels on the other things I am doing.  So it's a benefit, actually!  More soon...

jkrame1, 2018-02-05:
That is a very fair question! The answer is I did try the begin() before and after the .enable(), but it was before I narrowed down what I thought the issue might be, so it was during a period of distraction and undisciplined hacking. I can only remember that I did it because I remember moving begin() from the begin of the setup() to the end, thinking that the order might be important, but knowing that I didn't have an understanding of why exactly. In other words, it would be worth examining that again now.

kschaffer, 2018-02-05:
OK, I have reproduced the bug, so I see the problem, at least.  You may have already searched on this but I am thinking maybe this thread:
https://forum.pjrc.com/threads/38584-Audio-board-with-SD-card-and-concurrent-SPI-usage
may be relevant.  Anyway what I get from it is that I need to dig a little to understand the audio library's use of interrupts ... and I might need to wrap the SPI stuff in something more intelligent, for the Betweener.  We don't want to sacrifice this functionality - having the DACs running at some reasonable rate of control while also being able to process audio at full speed.  But it looks like it might get technical.  So... I'll see where it takes me!

kschaffer, 2018-02-09:
See thread:
https://forum.pjrc.com/threads/49562-Audio-functionality-and-SPI-communication-again!-(Teensy-3-2)
for an explanation of the issue, which is now fixed by reordering the calls to SPI.begin() and SPI.setMOSI.

Closed 2018-02-09.

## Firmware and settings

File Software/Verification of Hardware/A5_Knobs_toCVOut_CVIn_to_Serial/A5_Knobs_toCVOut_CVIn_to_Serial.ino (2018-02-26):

//Read the 4 knobs of the converter device using the 10-bit analogRead, 
//then convert the values from the 10-bit input range (0-1023)
//to the 12-bit output range (0-4015), then
//print the values to the 12-bit CV Outputs
//Read the CV inputs, print the values to the Serial Monitor

#include <SPI.h>

//One DAC is wired up to have chip select to Teensy digital pin 1
//the other to Teensy 2
int chip_select = 1;
int chip_select2 = 2;

//create variables to hold scaled knob readings
int scaled1 = -1;
int scaled2 = -1;
int scaled3 = -1;
int scaled4 = -1;

//sets the chip select to high to start
//and starts communicating over normal SPI pins
//which are pins 13 (clock) and 11 (MOSI)
//unless we set those to the alternate options
// 14 (clock) and 7 (MOSI), which is what we
//want if we are using the audio shield too

void setup() {
  pinMode(chip_select, OUTPUT);
  digitalWrite(chip_select, HIGH); // HIGH);
  pinMode(chip_select2, OUTPUT);
  digitalWrite(chip_select2, HIGH); // HIGH);

  SPI.setMOSI(7);
  SPI.setSCK(14);
  SPI.begin();
  
  Serial.begin(115200); //open serial port to receive values from knobs

}

void loop() {
//Read each knob and write its value to the Serial Monitor
  int  CurrentKnob1 = analogRead(12); //read knob 1 and store the reading in a value called "CurrentKnob1"
  scaled1 = map(CurrentKnob1, 0, 1023, 0, 4095);  //scale the value from a 10-bit value to a 12-bit value
  MCP4922_write(chip_select2, 1, scaled1); //Write the scaled value of knob 1 to OUTPUT 1


  int  CurrentKnob2 = analogRead(13);
  scaled2 = map(CurrentKnob2, 0, 1023, 0, 4095);
  MCP4922_write(chip_select, 0, scaled2);  //OUTPUT 2


  int  CurrentKnob3 = analogRead(11);
  scaled3 = map(CurrentKnob3, 0, 1023, 0, 4095);
  MCP4922_write(chip_select2, 0, scaled3); //OUTPUT 3


  int  CurrentKnob4 = analogRead(10);
  scaled4 = map(CurrentKnob4, 0, 1023, 0, 4095);
  MCP4922_write(chip_select, 1, scaled4);  //OUTPUT 4



  //Read each CV and write its value to the Serial Monitor
  int  CV1 = analogRead(7); //read knob 1 and store the reading in a value called "CurrentKnob1"
  Serial.print("1: ");                //print the number 1, a colon, and a space
  Serial.println(CV1);       //print the current value of knob 1

  int  CV2 = analogRead(6);
  Serial.print("2: ");
  Serial.println(CV2);

  int  CV3 = analogRead(3);
  Serial.print("3: ");
  Serial.println(CV3);

  int  CV4 = analogRead(2);
  Serial.print("4: ");
  Serial.println(CV4);

  delay(10); //wait for 100 milliseconds (.1s) so that we don't make too many readings and clog up the serial data line
}

//this is the DAC write function.  Pulls the chip select
//low in each write cycle and then sets it high again.
//the inscrutable stuff here is to get the right
//byte format for the chip
void MCP4922_write(int cs_pin, byte dac, int value) {
  byte low = value & 0xff;
  byte high = (value >> 8) & 0x0f;
  dac = (dac & 1) << 7;
  digitalWrite(cs_pin, LOW);
  SPI.transfer(dac | 0x30 | high);
  SPI.transfer(low);
  digitalWrite(cs_pin, HIGH);
}

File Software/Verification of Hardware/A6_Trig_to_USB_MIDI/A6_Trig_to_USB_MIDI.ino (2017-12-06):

// Trigs to USB MIDI

/*
  Triggers all generate notes over USB MIDI
  *    -> 60
  **   -> 61
  ***  -> 62
  **** -> 63
*/

// CV to USB MIDI
#include <SPI.h>
#include <Bounce.h>

// the MIDI channel number to send messages
const int channel = 1;


// Create Bounce objects for each button.  The Bounce object
// automatically deals with contact chatter or "bounce", and
// it makes detecting changes very simple.
Bounce trig1 = Bounce(0, 5);  // 1 = 1 ms debounce time
Bounce trig2 = Bounce(3, 5);
Bounce trig3 = Bounce(5, 5);
Bounce trig4 = Bounce(4, 5);

void setup() {
  Serial.begin(115200);

  pinMode(0, INPUT_PULLUP);  //set internal pullup resistors for Trigger inputs
  pinMode(3, INPUT_PULLUP);
  pinMode(5, INPUT_PULLUP);
  pinMode(4, INPUT_PULLUP);
  pinMode(8, OUTPUT);        //indicate on pin 13 that a Trig has been recieved
}

void loop() {

  usbMIDI.read();

  trig1.update();
  trig2.update();
  trig3.update();
  trig4.update();

  // Check each button for "falling" edge.
  // Send a MIDI Note On message when each button presses
  // Update the trig inputs only upon changes.
  // falling = high (not pressed - voltage from pullup resistor)
  // to low (pressed - button connects pin to ground)

  if (trig1.fallingEdge()) {
    usbMIDI.sendNoteOn(60, 99, channel);  // 60 = C4
    digitalWrite(8, HIGH);
  }
  if (trig2.fallingEdge()) {
    usbMIDI.sendNoteOn(61, 99, channel);  // 61 = C#4
    digitalWrite(8, HIGH);
  }
  if (trig3.fallingEdge()) {
    usbMIDI.sendNoteOn(62, 99, channel);  // 62 = D4
    digitalWrite(8, HIGH);

  }
  if (trig4.fallingEdge()) {
    usbMIDI.sendNoteOn(63, 99, channel);  // 63 = D#4
    digitalWrite(8, HIGH);
  }

  // Check each button for "rising" edge
  // Send a MIDI Note Off message when each button releases
  // For many types of projects, you only care when the button
  // is pressed and the release isn't needed.
  // rising = low (pressed - button connects pin to ground)
  // to high (not pressed - voltage from pullup resistor)
  if (trig1.risingEdge()) {
    usbMIDI.sendNoteOff(60, 0, channel);  // 60 = C4
    digitalWrite(8, LOW);
  }
  if (trig2.risingEdge()) {
    usbMIDI.sendNoteOff(61, 0, channel);  // 61 = C#4
    digitalWrite(8, LOW);

  }
  if (trig3.risingEdge()) {
    usbMIDI.sendNoteOff(62, 0, channel);  // 62 = D4
    digitalWrite(8, LOW);

  }
  if (trig4.risingEdge()) {
    usbMIDI.sendNoteOff(63, 0, channel);  // 63 = D#4
    digitalWrite(8, LOW);

  }
}  

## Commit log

2017-10-24 New files
    [Breakout Header Repeater.fzz, DAC Version B 1.0.0.fzz, DAC Version B 1.0.0.recoverfzz.fzz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]
2017-10-25 Moved DAC chip
    Moved DAC1 chip down a little to make it easier to insert next to DAC2
    [DAC Version B 1.0.3.fzz]
2017-10-25 Added Laser Cut Layout
    Forward and Reverse Engraving and liaser cut files
    [Breakout Header Repeater.fzz, DAC Version B 1.0.0.fzz, DAC Version B 1.0.0.recoverfzz.fzz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]
2017-10-25 Demo program with multiple simultaneous functions
    Introduce name.c - Header to name the MIDI device. Still doesn't work correctly
    [CV_to_USB_MIDI_RevB_1.0.2.ino]
2017-11-07 Stereo Expansion Board
    This is the layout for jacks and an expansion header to bring the Teensy Audio Shield's stereo I/O to the front panel.
    [Stereo I:O expansion.fzz]
2017-11-07 updated boards
    [DAC Version B 1.0.2(label change).fzz, DAC Version B 1.0.3.fzz]
2017-11-08 Updated Layout for PCB cutting
    [DAC Version B 1.0.3.fzz, Interface_VersionB_1.0.3.fzz]
2017-11-08 Created Capacitive sensor test header
    This is almost tall enough to be mounted in a Eurorack case. 128.5 mm is the correct hight for a Eurorack faceplate, but the FR1 from Bantam is only 127mm in its longest dimension. Like I said...experimental
    [2HP Eurorack Panel Expander.fzz]
2017-11-08 Added Gerbers
    [2HP Eurorack Panel Expander_contour.gm1, 2HP Eurorack Panel Expander_copperBottom.gbl, 2HP Eurorack Panel Expander_copperTop.gtl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]
2017-11-08 Small size updates
    [2HP Eurorack Panel Expander.fzz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]
2017-11-12 Created Example Code for Triggers to MIDI
    Four trigger inputs generate Note On messages for high signals, and Note Off messages (Note On messages with a velocity of 0) for low signals, using the Betweener Library. Note, trigger inputs are "a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
2017-11-12 Reorganized Folders
    [2HP Eurorack Panel Expander.fzz, Breakout Header Repeater.fzz, DAC Version B 1.0.0.fzz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]
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2017-11-14 reorganized file structure
    [DAC Version B 1.0.0.fzz, DAC Version B 1.0.1.fzz, DAC Version B 1.0.2(label change).fzz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]
2017-11-15 Reorganized Hardware folders to make them easier to navigate
    [DAC Version B 1.0.0.fzz, DAC Version B 1.0.1.fzz, DAC Version B 1.0.2(label change).fzz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]
2017-11-17 Added MIDI serial notes
    Hardware DIN MIDI must use UART pins in order to use the MIDI library. Teensy has alternate Rx and Tx pins available for Serial2 on 26 and 31, respectively. These we unused and available on the expan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
2017-11-17 Added Double-sided PCB layouts
    [DAC Version B 1.0.4.fzz, DAC Version B 1.0.5.fzz, Interface_VersionB_1.0.4.fzz]
2017-12-05 Updated Hardware Pin Assignments
    Production version of the board pin assignments updated
    [Breakout Header Repeater.fzz, DAC Version B 1.0.4_Fill.fzz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]
2017-12-06 Updated To Indicate Missing 5v
    The 5V Pin on the expander was left Unconnected in the first batch of Production Boards. This has been reflected in the header table.
2017-12-06 Created MIDI Expander with LED indictor
    The first version of a MIDI Expander with LED has been designed.
    [DIN MIDI Expander.fzz]
2017-12-07 Updated PCB
    Completed traces on PCB
    [DIN MIDI Expander.fzz]
2017-12-10 Working on Laser Cut Enclosure
    Added a work-in-progress design for a desktop-style enclosure that can include many additional features.
    [DAC Version B 1.0.5.fzz]
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2017-12-11 Organized Folders
    [DAC Version B 1.0.3.fzz, DAC Version B 1.0.4_Fill.fzz, Interface_VersionB_1.0.3.fzz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]
2017-12-11 Updated Readme to indicate current Hardware file
    Readme file now indicates the production version of the hardware. B 1.0.4_Fill
2017-12-12 Header Pin Correction
    LED resistor was moved to correct pin on the Expander Header.
    [DIN MIDI Expander.fzz]
2017-12-15 updated hardware and organized folders
    [Breakout Header Repeater.fzz, DAC Version B 1.0.0.fzz, DAC Version B 1.0.1.fzz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]
2017-12-18 Minor Updates
    [DAC Version B 1.0.5.fzz, DIN MIDI Expander.fzz]
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2017-12-18 added DIN MIDI and DIGIPOT support and some basic error printouts.
2017-12-29 Minor Changes for clarity
    These were updated a little while ago. Updates related to random, minor changes. sorry for the least useful comment so far...
    [DIN MIDI Expander.fzz, Interface_VersionB_1.0.5.fzz]
2018-01-02 added v0.1 alpha for generative sequencer
    non-working alpha.
    Currently the trigger reading does not work in the Betweener library. I have tested my hardware using both the Bounce lib + Bounce2 lib.
    Line 263 of Betweener.h updated 12/23/17
    should read
    Bounce trig1 = Bounce();
    for Bounce2 library. Still doesn't work though.
    [generativeSeq.ino]
2018-01-03 Organized File and Updated Knob Hole Size
    Layer organization and labeling improved. Hole size for knobs increased slightly from about .24in to .26in diameter.
2018-01-03 Clarify random gate sequencer
    Simplified randomizeGateSeq();
    Updated Bounce syntax.
    Reads only triggers in loop, knobs in randomizer.
    Removed Wire.h library.
2018-01-05 New Board Designs Updated
    [DAC Version B 1.0.5.fzz, DAC Version B 1.0.5_Filled.fzz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]
2018-01-12 Version B 1.0.5 Updated to Production Version
    -100Ω resistors added to CV output.
    -Traces were moved in from board edges and Ground Fill updated.
    -78l05 added to provide 5V power to the board
    [DAC Version B 1.0.5.fzz, DAC Version B 1.0.5_Filled.fzz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]
2018-01-22 Board Updated to first offical release - 1.1.0 to correct Ground Fill Error
    The Ground Fill was inappropriately connected to the voltage regulator's Vout pin. That has been corrected and final board design is now 1.1.0.
    [DAC 1.1.0.fzz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]
2018-01-22 Added LED indicator
    LED now toggles on when a test mode is selected. It toggles off when test mode is exited and user returns to the menu.
2018-01-24 Updated Layout for cutting order improvements
    Interior vector cuts have been changed to Magenta (255, 0, 255) so that they will always cut before the orange outlines (255, 102, 0) on the Trotec Laser Cutters at the AOC at SAIC.
2018-02-03 Comment Grammer Corrected
    A comment ended in a preposition. Yuck.
    [TouchReadSerial-experimental_2hp_expander.ino]
2018-02-05 First Example of Betweener Library with Audio Shield - **issues here
    Example of using Triggers 1 - 4 to playback samples held in program memory. Uses the Teensy Audio Shield. Currently has conflict with betweener library where the begin(); function restarts the SPI and conflicts somehow with (probably) the SGTL5000 Codec. SPI.begn() must be commented out of the betweener .cpp library file in order to get this example working.
2018-02-05 Fixed LED Indicator issue
    LED pin is now set to OUTPUT.
    Added comments for clarity.
2018-02-09 fixed issue with order of SPI.begin() call; cleaned up some variable names and comments.
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2018-03-07 Names changed to comply with Arduino restrictions
    Sketches were numbered, which caused issues with some versions of Arduino. Now they start with letters.
    [A2_Knobs_to_Serial.ino, A3_Knobs_to_CV.ino, A4_CVIn_to_Serial.ino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]
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2018-03-16 Corrected Sketch Names
    Changed some sketch names to comply with Arduino formatting conventions.
    [A1_DAC_Verification.ino, A5_Knobs_toCVOut_CVIn_to_Serial.ino]
2018-03-26 Enclosure File Updated for better laser cut sequencing
    Magenta 255, 0, 255 added to outlines so internal cuts happen before outlines are cut (orange 255, 102(?), 0).
2018-03-26 D2 updated so the first 5 octaves of MIDI notes are roughly 1v/oct
    notes 0 - 60 are now mapped to volatages from 0v - 5v for a -roughly- 1 volt per octave scaling for the first five octaves of midi notes. Notes outside of that range will wrap around.
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
